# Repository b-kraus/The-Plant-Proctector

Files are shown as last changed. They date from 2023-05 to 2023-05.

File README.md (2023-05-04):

# The-Plant-Proctector
Group 40: David Myers, Beth Kraus final project.

This project will help a plant owner take care of their plant by being notified if the humidity or soil moisture of said plant is not optimal. A buzzer, and a notification via wifi will trigger so that the user can tend to their plant.

Schematic Information:
See attached docs for schematic information.

C-Code Information: 
This is the combined code for the Plant Proctector Project.  When I was designing the code, I first designed each part seperately and tested them accordingly. Both sensors requried calibration in order to get the right result.  After I finished testing each part, I put the code together and tested it as a whole. 

The code can be broken down into four parts:
- Buzzer
- DHT11
- Soil Moisture Sensor
- UART

Before I explain how the code funtions, I must explain how the data is stored for each sensor.  The soil moisture sensor is stores a number value and you are suppose to calibrate it to produce a percent. The DHT11 stores data in 40 bit, temperature high, temperature low, humidity high, humidity low, and a checksum. High is the whole number part of the number and the low is the decimal part.

The buzzer code is very simple, just a simple if statement that will cause the buzzer to sound if the hh, th, moisturePercent go below the set range. 

The DHT11 does not use the ADC but uses a if statement. First it reads the hh, then hl, and so on.  It then adds the data and compares it to the check sum.

The Gitkin Soil Moisture works by creating a value.  Using the ADC, we are able to collect this value. In order to get the percentage we need to calibrate this value. First you take a reading of the sensor dry and record this data.  Then we take a reading of the sensor in water.  Final we put these values in the following formula:  moisturePercent = ((DRY_VALUE - adcResult ) * 100.0) / (DRY_VALUE - WET_VALUE).

UART sends a string stating what the problem is if the sensor does not fall within the range.

ONE IMPORTANT NOTE: Both sensors use TB2 that are configured different, but to get around this, I made an if statement that will bounce between the sensors when collecting data and each time it switches it reconfigures it. 

All Wifi code was provided.

I had several issues with the wifi and plan to investigate further on how we can debug these issues. 

PCB Information:
The PCB was specifically designed for this project using a provided template from the class. It uses an MSP430 microcontroller soldered onto the board and is powered by a micro USB header at 5 volts. It also utilizies a copper pour on its bottom layer as this reduced complexity and gives us an entire ground layer to work with. The PCB underwent various revisions, however we ultimately decided on our final design as it made soldering easier going forward.

The PCB encountered some problems in our final design. We could not correctly flash the MSP430 MC on our board. We think we may have needed more pins to work with as we only had 4 set up. This error would require us to reprint the board which we did not have enough time for. Despite this short coming, we were able to confirm everything connected properly and the board was able to recieve and show that is was in fact being powered. However not being able to flash it was a major set back.

Another issue regarding the PCB was our buzzer. In our design, a buzzer was supposed to go off when pin P1.5 sent it a signal. However we could not replicate this effect. This is likely due to a circuit we removed from the final design. Originally, we were advised to build a BJT circuit on our PCB. However we scrapped it, trying to keep our board more clean and simple. This may have been what resulted in our buzzer not working correctly. We could only get it to make a faint noise.

Going forward, the PCB design needed more time and understanding to be developed fully. Further research, investigation, and experience would have yielded a better result.

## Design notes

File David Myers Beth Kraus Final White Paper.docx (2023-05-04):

The Plant Protector

Group 40: David Myers, Beth Kraus

5/4/23, Intro to Embedded Systems ECE 09342 Section 2

Contribution Chart:

| David Myers | Beth Kraus
Initial Research | X | X
Block Diagram and UML | X | X
PCB Design | X
Soldering | X
Coding | | X
Analyzing Results | X | X
Research Related to Project that Helps Report Writing | X | X
Writing Report | X | X
Making Presentation Slides | X | X

# Abstract/Goal:

Plants are an important part of the environment around us, yet we as humans struggle to care for them. Have you ever gotten a houseplant or a garden plant and two weeks later it's dead? In those two weeks, the plant was undergoing constant changes yet from our view, it did not look like it changed. Then suddenly it's dead. But what if we can chart those changes and receive notifications when the plant needs changes to its environment? For our project, we decided to design an embedded system that will help plant owners take care of their potted plants at home.

# Background/Introduction:

The Plant Protector is a system that uses sensors programmed in C and utilizing a custom PCB to give a user feedback about the health of their house plants, and what they should do to take care of it. When the plant’s needs are not being met, an alarm is raised, and a message is sent to the user. While it is difficult to track down the origin of plant care devices like this one, it is safe to say that many variations of them have been developed over time by independent engineers and businesses alike. A device like this takes many shapes and sizes but generally they all serve a similar function, that being to help users keep their plants healthy with minimal attention needed.

# Methodology and System Design:

PCB Design

1. We were originally going to make a board that functions depending on the MSP430 development board, however we scrapped the idea early on.
2. The next redesign was made to be standalone, with an MSP430 microcontroller soldered onto the PCB itself, removing the need for a dev board. However, used custom dimensions that would have made soldering more difficult.
3. Final revision utilized a given schematic with modifications made so it fit our needs better.

Design Choices for Final PCB Revision

1. Copper Pour on back layer: We utilized a copper pour on our PCB to help reduce heat and complexity of the design. This pour acts as our ground, and greatly reduces the number of traces needed.
2. Using the given schematic: Using the provided schematic to design our PCB off helped greatly with soldering components later in the project as there was no need to worry about custom dimensions. This also guaranteed us a compact design.
3. Independent System: The final design contains a Micro USB header that sends 5V to the system and a 1x4 pin connection for flashing the microcontroller. This allows the system to function on its own without the help of a dev board.

C Code

1. We initialized the GPIO pins needed for our board. See the following list of the pins used and what was connected to them:
  a. Pin 1.7 = RX
  b. Pin 1.6 = TX
  c. Pin 1.5 = Buzzer
  d. Pin 5.0 DHT 11
  e. Pin 5.1 Soil Moisture
2. We started the ADC and set it up to be a 2 channel ADC for the two sensors.
3. We started and setting up the UART
4. UART sends data using the WIFI module
5. We will have an interrupt with the following conditions in it
  a. If the temperature goes below 16 C or above 30 C then the buzzer will go off
  b. If the humidity goes below 30% or above 50%, then the buzzer will go off
  c. If the soil moisture goes below, 20 % or above 40%, then the buzzer will go off

Major Components

- DHT11: We chose to use the DHT11 due to its availability and compatibility with C coding. This component acts as our temperature sensor.
- Buzzer: We chose to use a buzzer to inform the plant’s owner that the conditions are not being met.
- Soil Moisture Sensor: We chose this sensor because of its availability.
- ESP8266: We chose to use the smaller form of the ESP8266 because of size and of convenience when coding. This wifi module allows us to send notifications to the user.

## Functional block diagram

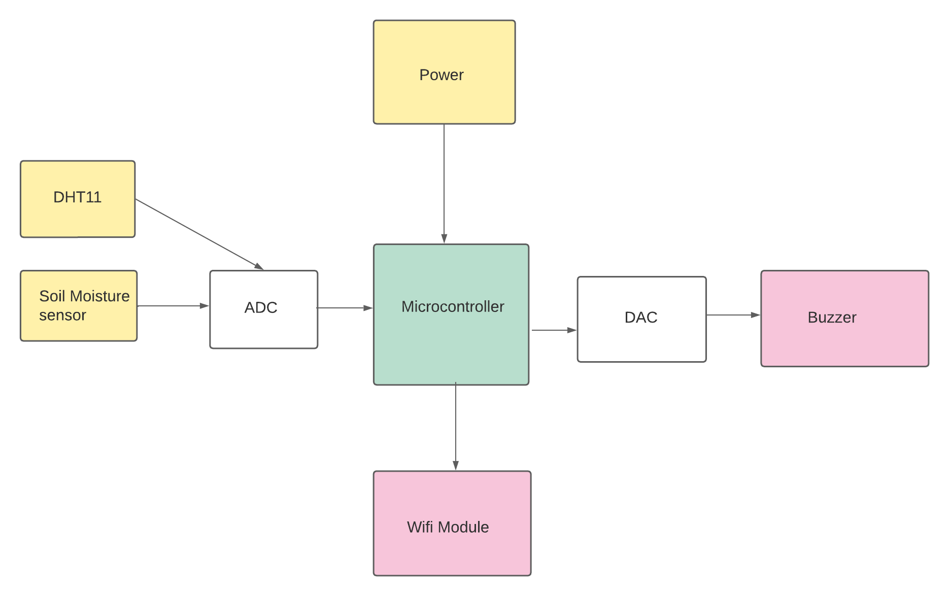
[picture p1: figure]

## UML Activity Diagram

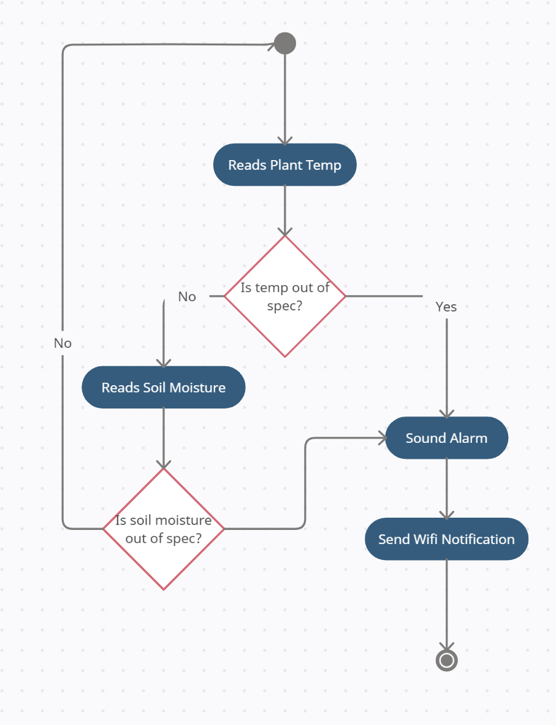
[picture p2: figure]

## Parts List and Design cost

Part | Quantity | Price | Source
MicroUSB header | 1 | $1.01 | 1050170001 Molex | Connectors, Interconnects | DigiKey (https://www.digikey.com/en/products/detail/molex/1050170001/2350832?s=N4IgTCBcDaIIwAYCsC4HYC0DtxAXQF8g)
100nF capacitor | 1 | $0.23 | Rowan ETR | Inventory (https://etr.rowan.edu/inventory/part/1340)
10uF capacitor | 1 | $0.51 | Rowan ETR | Inventory (https://etr.rowan.edu/inventory/part/470)
1nF capacitor | 1 | $0.35 | Rowan ETR | Inventory (https://etr.rowan.edu/inventory/part/544)
1uF capacitor | 2 | $0.96 | Rowan ETR | Inventory (https://etr.rowan.edu/inventory/part/563)
5.1k resistor | 1 | $0.10 | Rowan ETR | Inventory (https://etr.rowan.edu/inventory/part/89)
47k resistor | 1 | $0.10 | Rowan ETR | Inventory (https://etr.rowan.edu/inventory/part/112)
1x40 Row Female Headers | 1 | $3.75 | Rowan ETR | Inventory (https://etr.rowan.edu/inventory/part/843)
1x40 Row Male Headers | 1 | $0.33 | Rowan ETR | Inventory (https://etr.rowan.edu/inventory/part/1592)
Temperature/Humidity Sensor | 1 | $5.66 | DHT11 UNIVERSAL-SOLDER Electronics Ltd | Sensors, Transducers | DigiKey Marketplace (https://www.digikey.com/en/products/detail/universal-solder-electronics-ltd/DHT11/16822119)
Soil Moisture Sensor | 1 | $8.68 | Rowan ETR | Inventory (https://etr.rowan.edu/inventory/part/1891)
Wifi Module | 1 | $7.50 | Rowan ETR | Inventory (https://etr.rowan.edu/inventory/part/1515)
PCB | 1 | $5 | NA
Microcontroller | 1 | $3 | NA
Buzzer | 1 | $2.99 | Amazon.com: Fielect 2Pcs 100dB Buzzer Alarm Electronic Beep Buzzer DC 3-24V SFM-27 Active Piezo Buzzer Continuous Sounder Electronic Buzzer Alarm Black : Electronics (https://www.amazon.com/Fielect-Electronic-Continuous-Piezoelectric-Sensitivity/dp/B0838Z8LTS?s=industrial)
| Total Cost | $40.17

# Experimental Set Up and Results:

## Schematic:

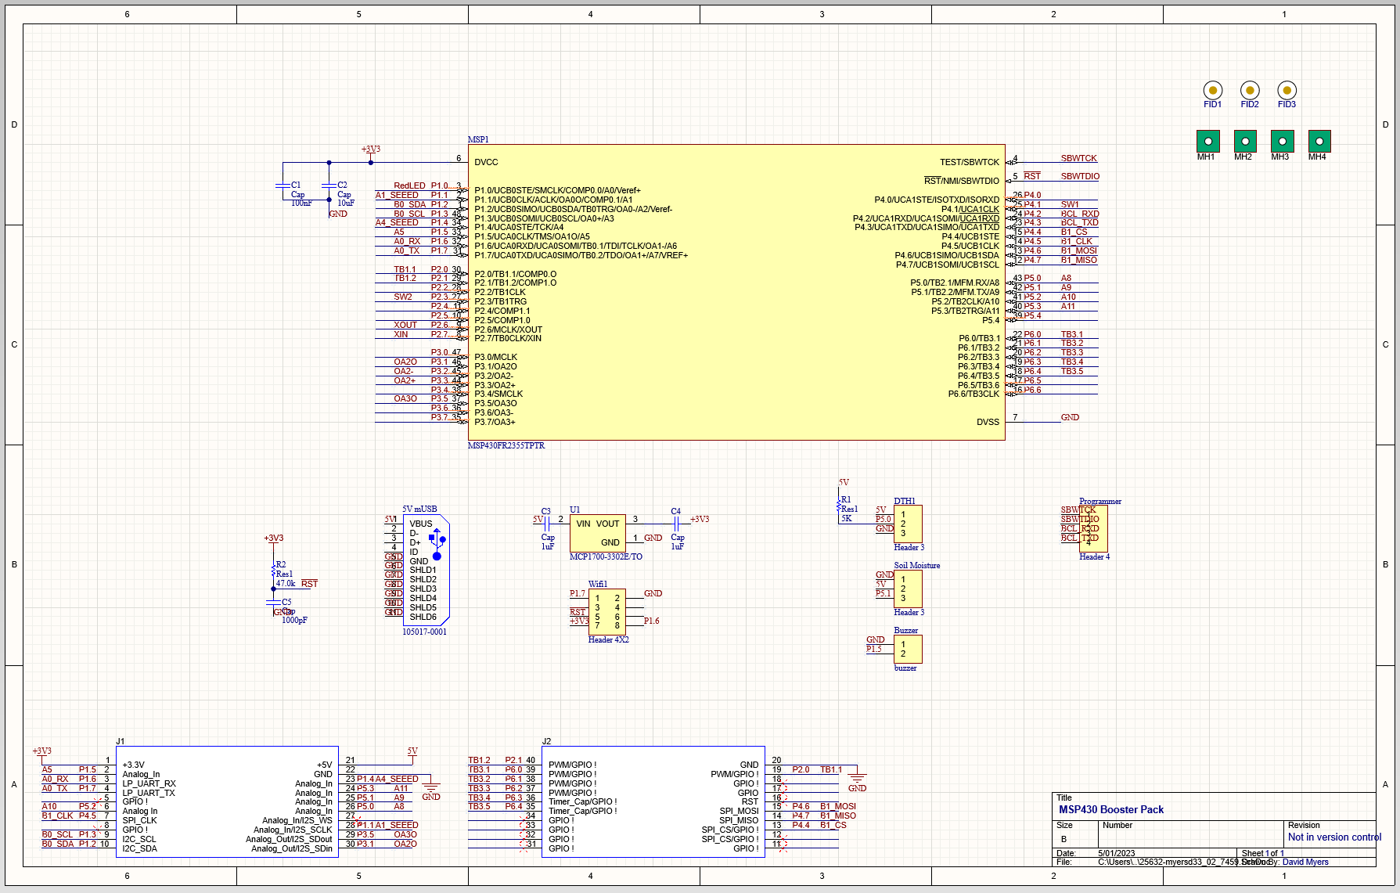
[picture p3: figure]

## Soldered PCB connection with MSP430:

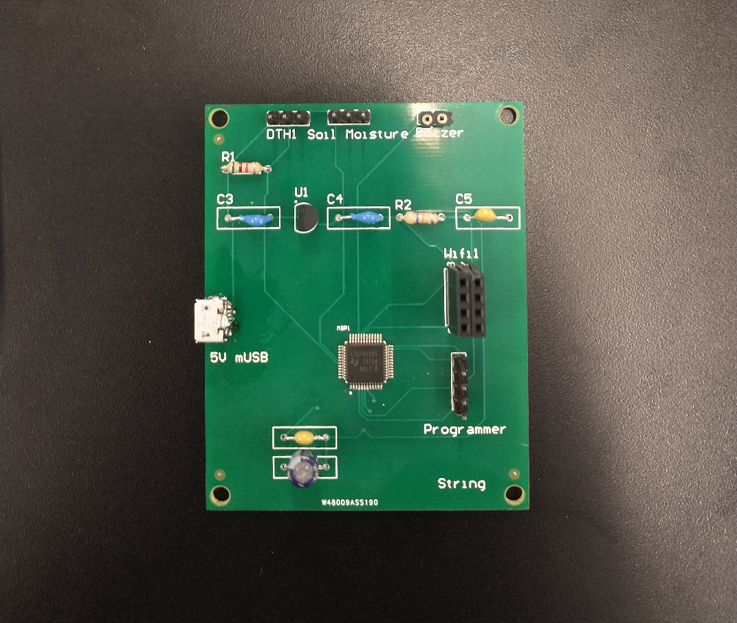
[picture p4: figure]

## Results from ThingSpeak

Unfortunately, we did not have time to finish the wi-fi configuration for our project. If it did work, it would have sent us an alert notifying us of the problem the plant is facing.

# Conclusion/Future Work

In conclusion, we designed and built a simple proof of concept idea that helps a user maintain plant health by reading plant vitals through sensors and relaying that information back to the user via wi-fi and actuation all utilizing C programming. We gained experience on the entire engineering design process, along with various other skills. We learned about troubleshooting C code and PCB design along with a deeper understanding of the software we were instructed to use. Going forward, we would like to make a more robust design with more features. Given our lack of experience in some areas and time limitations, we had to cut several design choices we planned originally. Some features such as humidity reading, and automated watering capabilities were removed because of this. In the future, we would love to incorporate these features and several others to make a more complex device that could be applied to not just house plants, but much larger areas such as farms or greenhouses.

# References

Acta Horticulturae. www.actahort.org/members/showpdf?booknrarnr=881_111.

Ag, Advancing Eco. “About.” Advancing Eco Ag, www.advancingecoag.com/pages/about.

# Appendix

b-kraus/The-Plant-Proctector: To defend those plants in need (github.com) (https://github.com/b-kraus/The-Plant-Proctector)

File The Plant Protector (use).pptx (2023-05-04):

## The Plant Protector

By: David Myers and Beth Kraus

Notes: dave

## Outline

- Overview/Goals
- Background
- System Operation/Block Diagram
- BOM
- Major Components
- Methods (PCB)
- Methods (Code)
- Timeline
- Progress
- UML Activity Diagram
- Demo

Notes: dave

## Overview/Goal

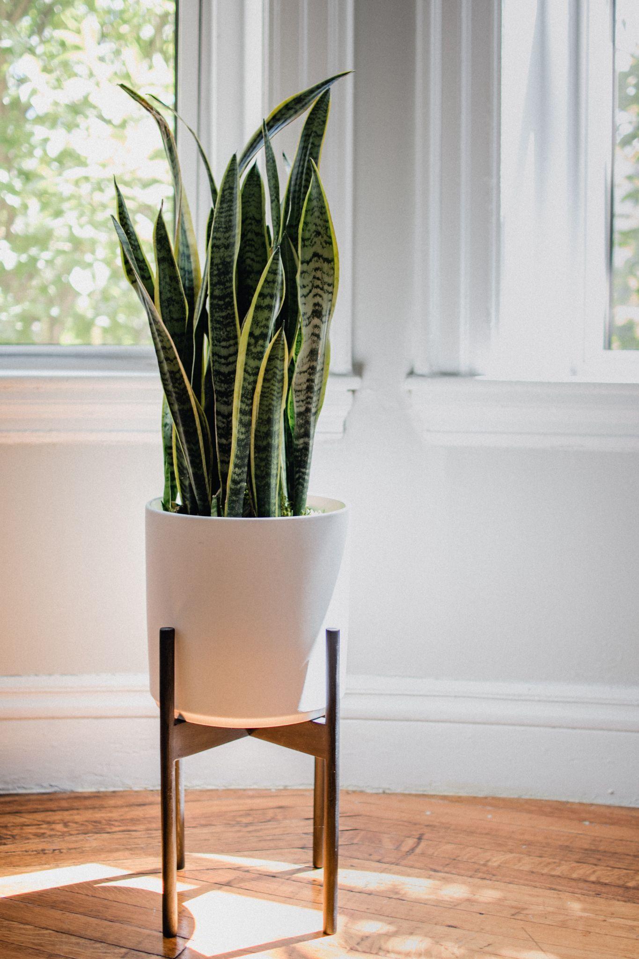
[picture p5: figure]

Image from: Unsplash.com

- People easily forget about their house plants which leads to them dying
- We designed a system that lets users know the problems their plant is facing
- Uses sensors to read plant vitals
- Notifies user of issues with buzzer and wifi notification

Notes: dave

## Background

- Difficult to trace the first plant care system like this
- Indoor plants provide several benefits to humans [1]
  - Cleaner air
  - Feeling calm
  - Reduce stress
  - Improved productivity
- Plant care devices exist all over the world in different shapes and sizes
  - Advancing Eco Agriculture offers systems that helps plants by monitoring soil health [2]

[1] Acta Horticulturae (https://www.actahort.org/members/showpdf?booknrarnr=881_111)
[2] about - Advancing Eco Ag (https://www.advancingecoag.com/pages/about)

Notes: beth

## System Operation/Block Diagram

- Plant Protector gives the user vitals of the plant it is connected to
- Uses an MSP430 microcontroller for operation
- Checks plants surrounding temperature and its soil moisture
- Sensors feed data to the microcontroller
- If the sensors relays data not within our set parameters two things occur:
  - Alarm on the module sounds
  - User gets a notification via wifi


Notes: dave

## Bill of Materials

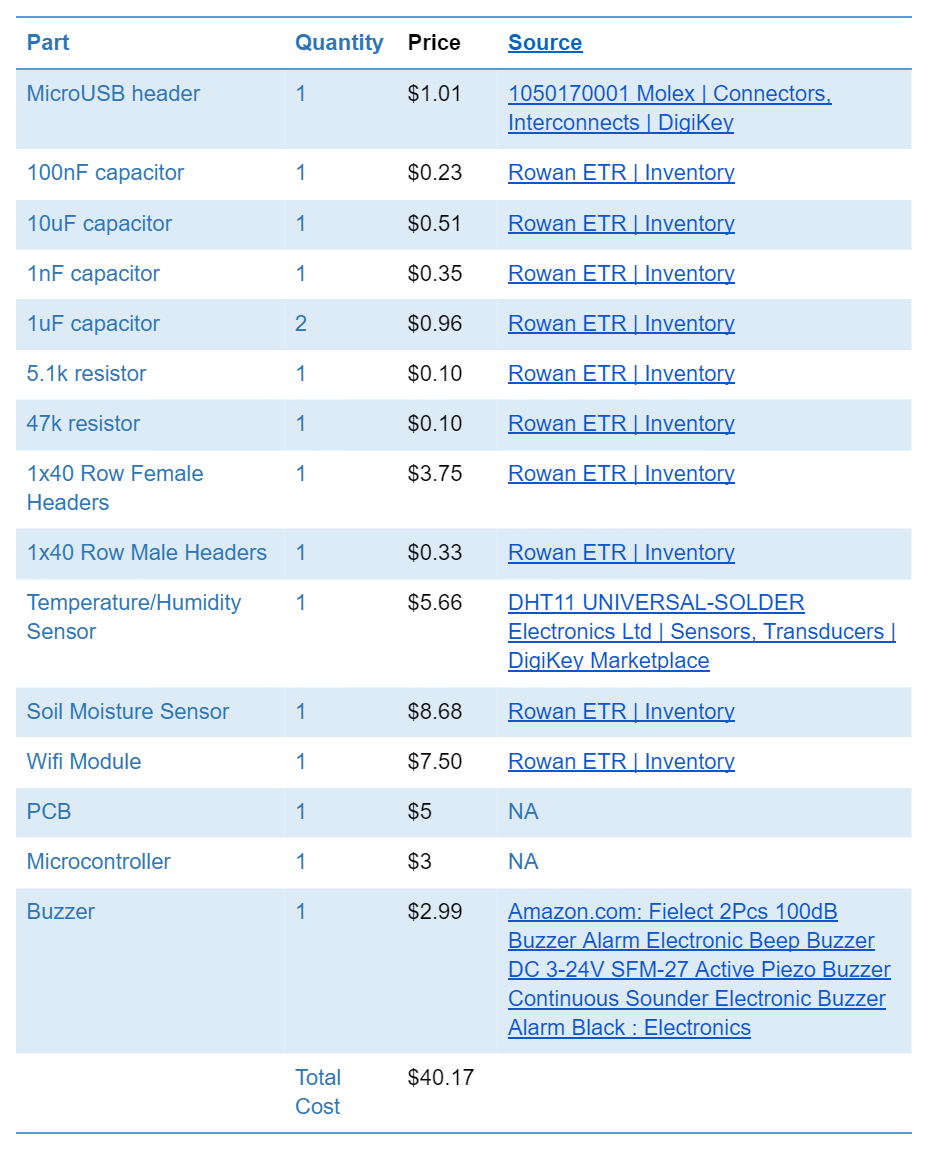
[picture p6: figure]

- Primarily used school resources
- Generally cheap components
- Total cost was $40.17

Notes: beth

## Major Components

(Components are displayed in order left to right)
DHT11: Temperature sensor. Chosen because of availability and compatibility with C coding.
EK1940: Soil moisture sensor. Chosen because of availability and ease of use.
Buzzer: Generic buzzer to act as a physical mean of communication to the user if the wifi fails.
ESP8266: Wifi Module. Allows us to wirelessly notify the user of plant issues. Chosen because of small form factor and user friendly.

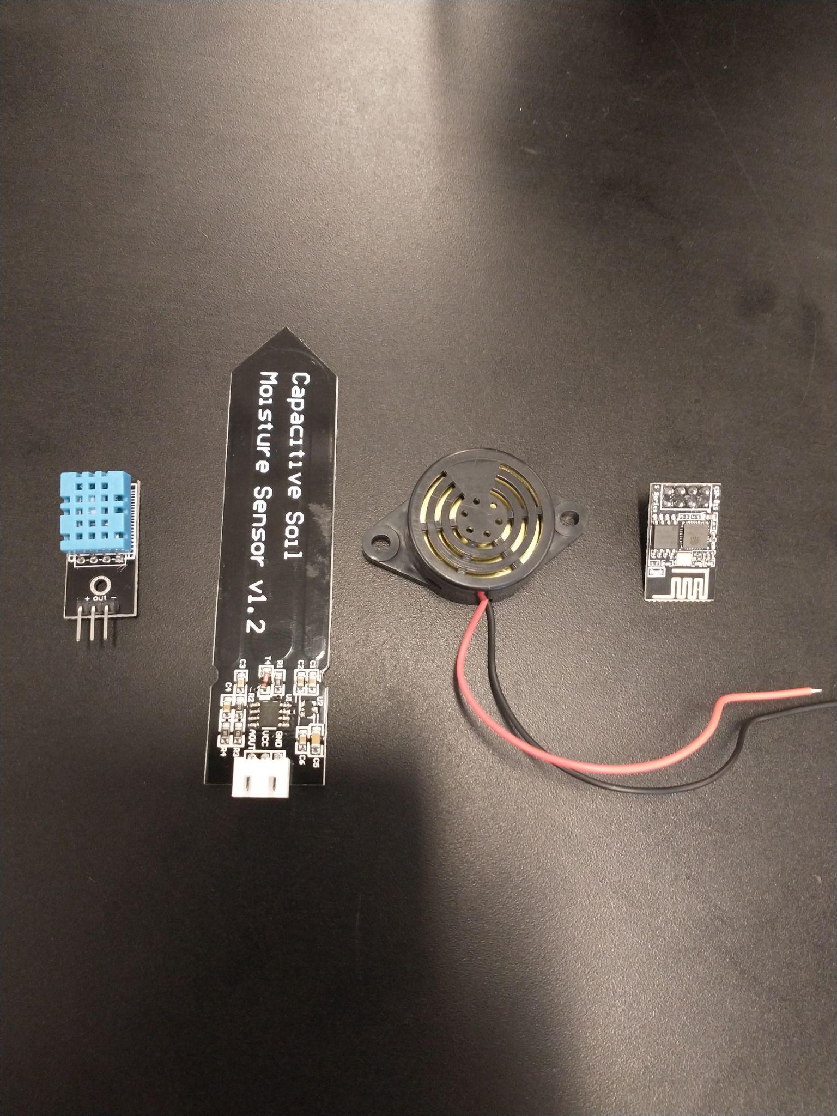
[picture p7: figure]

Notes: dave

## Methods (PCB)

- PCB underwent several revisions
  - 1st design required MSP430 dev board. Design was scrapped early on for better options
  - 2nd design was independent with MC soldered on. However used custom dimensions. Scrapped due to potential pick and place problems.
  - Final design used given schematic with modifications made. Allowed system to be independent and easy to work with.
- Final Design Choices
  - Copper pour on back as ground layer. (reduced trace complexity)
  - Using provided schematic. (made project significantly easier going forward)
  - Independent System. (Only needs to be flashed and powered to operate. No dev board needed)

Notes: dave

## PCB

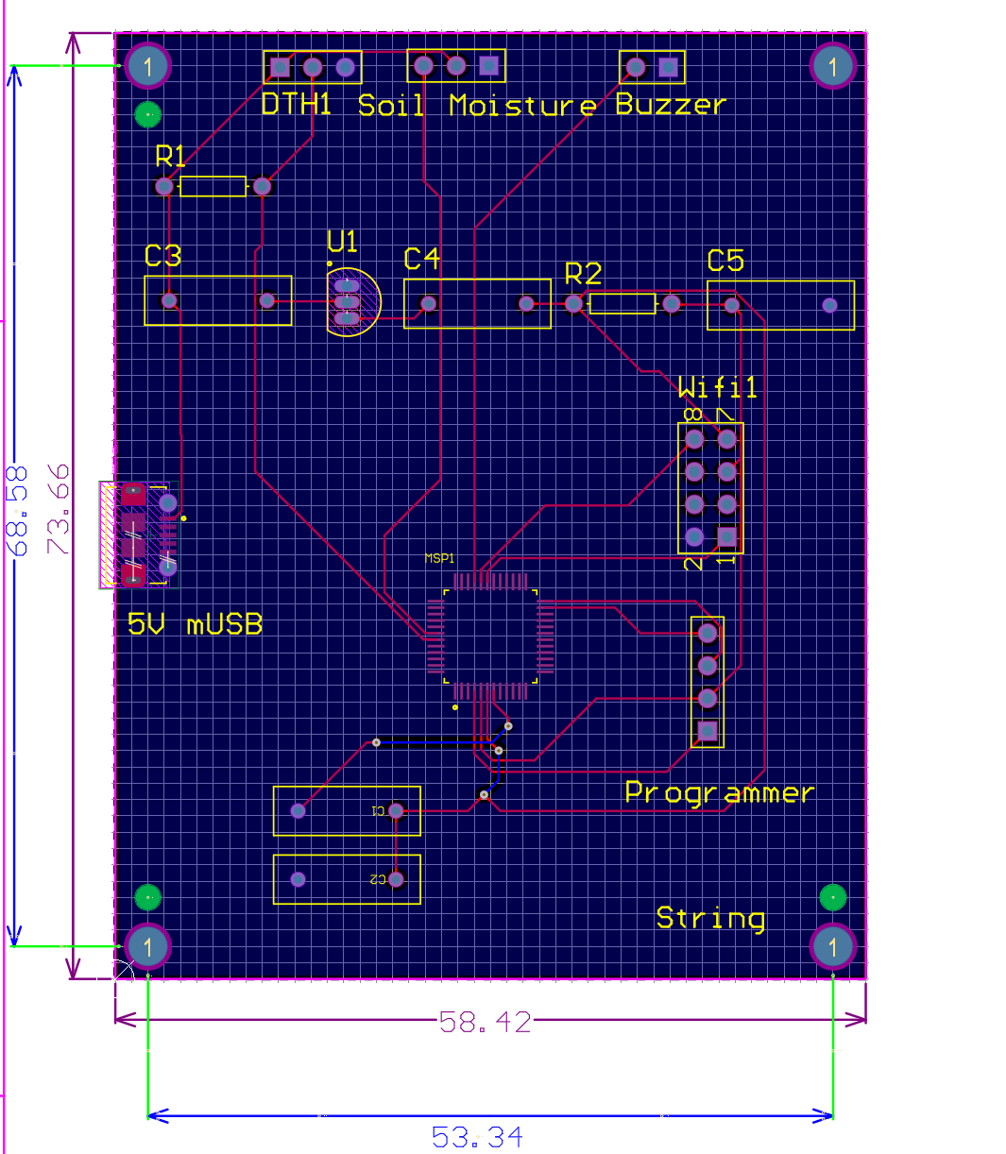
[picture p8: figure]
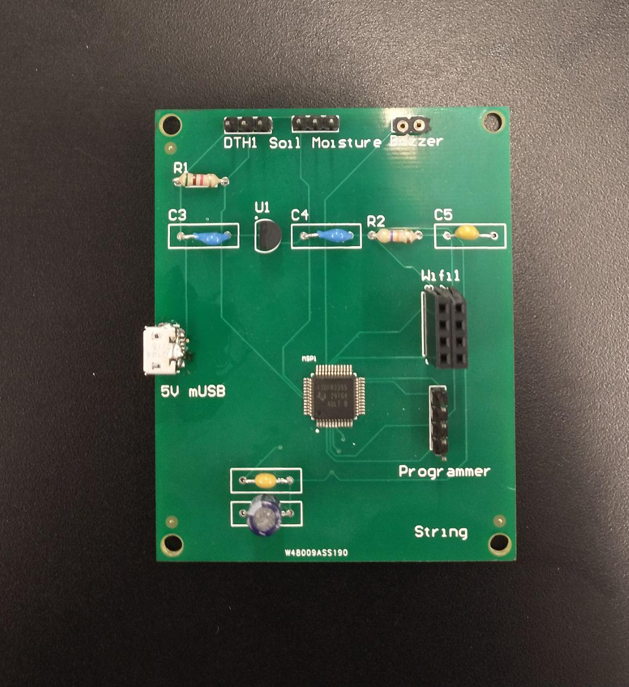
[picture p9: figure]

## Methods (Code)

- First, Initialize all GPIO Pins
  - Pin 1.7 = RX
  - Pin 1.6 = TX
  - Pin 1.5 = Buzzer
  - Pin 5.0 DHT 11
  - Pin 5.1 Soil Moisture
- Starting and setting up a 2 channel ADC for the sensors
- Starting and setting up the UART
- UART sends data using the WIFI module
- Interrupt with the following conditions in it
  - If the temperature goes below 16 C or above 30 C then the buzzer will go off
  - If the soil moisture goes below, 20 % or above 40 %, then the buzzer will go off
- b-kraus/The-Plant-Proctector: To defend those plants in need (github.com) (https://github.com/b-kraus/The-Plant-Proctector)

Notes: beth

## Timeline

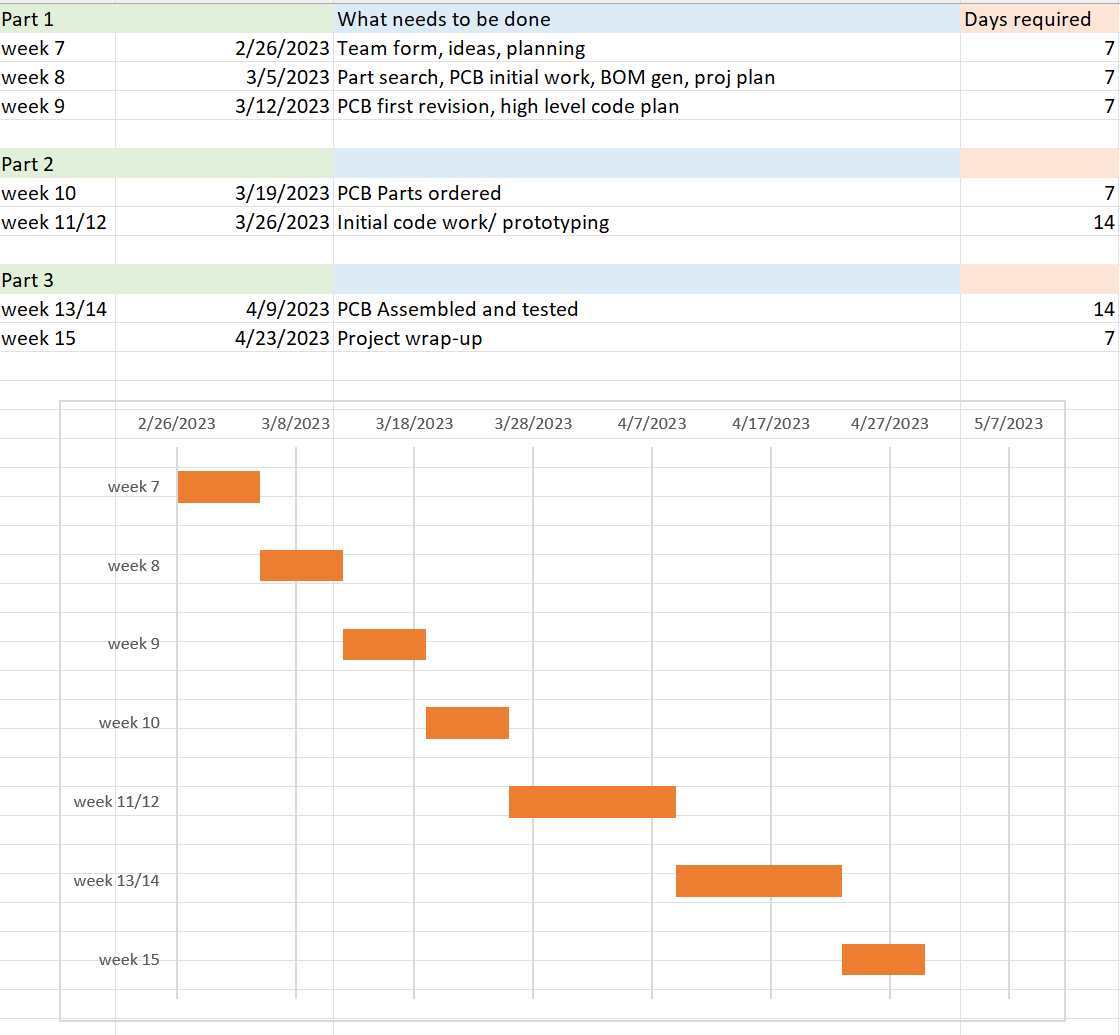
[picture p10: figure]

Part 1: Planing, finding parts, 1st PCB revision
Part 2: Ordering parts, prototyping and code work begins
Part 3: Assembly and testing

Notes: dave

## Progress

Completed Tasks
- PCB design
- Components ordered
- Assembly
- Temperature and soil moisture readings

Remaining Tasks
- Board needs a redesign
- Wi-Fi (Thingspeak channel)
- DHT11
- Flashing board

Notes: beth

## UML Activity Diagram


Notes: beth

## Demonstration

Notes: dave

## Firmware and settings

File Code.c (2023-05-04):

#include <msp430.h>
#include <stdint.h>
#define BAUDRATE 115200    // desired baud rate
#define SMCLK_FREQ 1000000 // SMCLK frequency
int m=0;
volatile unsigned int temp[50];
volatile unsigned int diff[50];
volatile unsigned int i=0;
volatile unsigned int j=0;
volatile unsigned char hh = 0;
volatile unsigned char hl = 0;
volatile unsigned char th = 0;
volatile unsigned char tl = 0;
volatile unsigned char checksum = 0;
volatile unsigned char check = 0;
volatile unsigned char dataok = 0 ;
volatile uint16_t adcResult;
float moisturePercent;
float DRY_VALUE = 890;
float WET_VALUE = 311;

void UART_init() {
  // Set pins 1.6 and 1.7 as UART pins
  P1SEL0 |= BIT6 + BIT7;
  P1SEL1 &= ~(BIT6 + BIT7);

  // Set the baud rate and other UART parameters
  UCA0CTLW0 |= UCSWRST;
  UCA0CTLW0 |= UCSSEL__SMCLK;  // Use SMCLK as clock source
  UCA0BRW = SMCLK_FREQ / BAUDRATE;  // Set the baud rate
  UCA0CTLW0 &= ~UCSWRST;  // Release the UART from reset
}

void UART_send_char(char c) {
  while (!(UCA0IFG & UCTXIFG));  // Wait for TX buffer to be empty
  UCA0TXBUF = c;  // Send the character
}

void UART_send_string(const char* str) {
  while (*str) {  // Loop until null-terminator is reached
    UART_send_char(*str);  // Send the current character
    str++;  // Move to the next character
  }
}

void main(void)
{
    WDTCTL = WDTPW | WDTHOLD;   // stop watchdog timer
    PM5CTL0 &= ~LOCKLPM5;
    UART_init();
    P1DIR |= BIT5;
    P1OUT &= ~BIT5;
    P5DIR |= BIT0;
    P5OUT &= ~BIT0;

    __delay_cycles(20000);

    P5OUT |= BIT0;

    __delay_cycles(5);

    P5DIR &= ~BIT0;
    P5SEL0 |= BIT0;
    P5SEL1 &= ~BIT0;


    ADCCTL0 |= ADCSHT_2 | ADCON; // 16 ADCCLK cycles for sample and hold time, ADC ON
    ADCCTL1 |= ADCSHP; // ADCCLK is used as the sampling timer
    ADCCTL2 |= ADCRES; // 12-bit resolution
    ADCMCTL0 |= ADCINCH_9; // Select channel A5 for ADC input
    ADCCTL0 |= ADCENC; // Enable conversion



    _enable_interrupts();

   while(1){

  if (m==0)
  {
         TB2CTL = TBSSEL_2|MC_2|TBCLR;
         TB2CCTL1 = CAP | CCIE | CCIS_0 | CM_3 | SCS ;

        if (i >= 40){
            for (j = 1; j <= 8; j++){
                if (diff[j] >= 100)
                    hh |= (0x01 << (8-j));
            }
            for (j = 9; j <= 16; j++){
                if (diff[j] >= 100)
                    hl |= (0x01 << (16-j));
            }
            for (j = 17; j <= 24; j++){
                if (diff[j] >= 100)
                    th |= (0x01 << (24-j));
            }
            for (j = 25; j <= 32; j++){
                if (diff[j] >= 100)
                    tl |= (0x01 << (32-j));
            }
            for (j = 33; j <= 40; j++){
                if (diff[j] >= 110)
                    checksum |= (0x01 << (40-j));
            }
            check = hh+hl+th+tl;
            if (check == checksum)
                dataok = 1;
            else
                dataok = 0;
        }
        if (th<16, th>30,hh<30, hh>50)
        {
            if (th < 16)
               { UART_send_string("It's too cold!\r\n"); }
            else if (th > 30)
               {UART_send_string("It's too hot!\r\n");}
            else if (hh > 30)
               {UART_send_string("I need more humidity!\r\n");}
            else if (hh < 50)
               {{UART_send_string("Please lower the humidity!\r\n");}
            P1OUT ^= BIT5;
           __delay_cycles(50);
           P1OUT &= ~BIT5;
           __delay_cycles(500);
        }
        m=1;
  }
  else
  {
              TBCTL = TBSSEL__ACLK | MC__CONTINUOUS; // Select ACLK as clock source, continuous mode
              TBCCR0 = 32768; // Set period to 1 second
              TBCTL |= TBCLR; // Clear timer
              ADCCTL0 |= ADCSC; // Start conversion
              __delay_cycles(1000); // Wait for ADC result to be ready
              adcResult = ADCMEM0; // Store ADC result
              moisturePercent = ((DRY_VALUE - adcResult ) * 100.0) / (DRY_VALUE - WET_VALUE);
              if (moisturePercent < 20, moisturePercent > 40)
              {        if (moisturePercent < 20)
                          { UART_send_string("Please Water Me!\r\n"); }
                       else if (moisturePercent > 40)
                       {UART_send_string("Please Drain My Water!\r\n");
                       }
                       P1OUT ^= BIT5;
                       __delay_cycles(50);
                       P1OUT &= ~BIT5;
                       __delay_cycles(500);
                    }
              m=0;
    }
   }
}
}
#pragma vector = TIMER2_B1_VECTOR
__interrupt void Timer_B2(void){
    temp[i] = TB2CCR1;
    i += 1;
    if (i>=2) diff[i-1]=temp[i-1]-temp[i-2];
    TB2CCTL1 &= ~CCIFG ;
}

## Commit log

2023-04-03 added pcb documents
    [MSP430 Booster Pack.PrjPcb, NewFinalProj.PcbDoc, NewFinalProj.SchDoc]
2023-04-30 Final schematic and PCB designs
    [25632-myersd33_02_7459.PcbDoc, 25632-myersd33_02_7459.SchDoc]
